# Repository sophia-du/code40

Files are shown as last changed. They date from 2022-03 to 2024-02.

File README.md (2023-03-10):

# code40
Pro-Micro compatible 40% ortholinear keyboard
- [Case Specifications](https://github.com/sophia-du/code40/blob/main/case/README.md)
- [PCB Specifications](https://github.com/sophia-du/code40/blob/main/pcb/README.md)
- [Firmware](https://github.com/sophia-du/code40/blob/main/qmk/README.md)
#
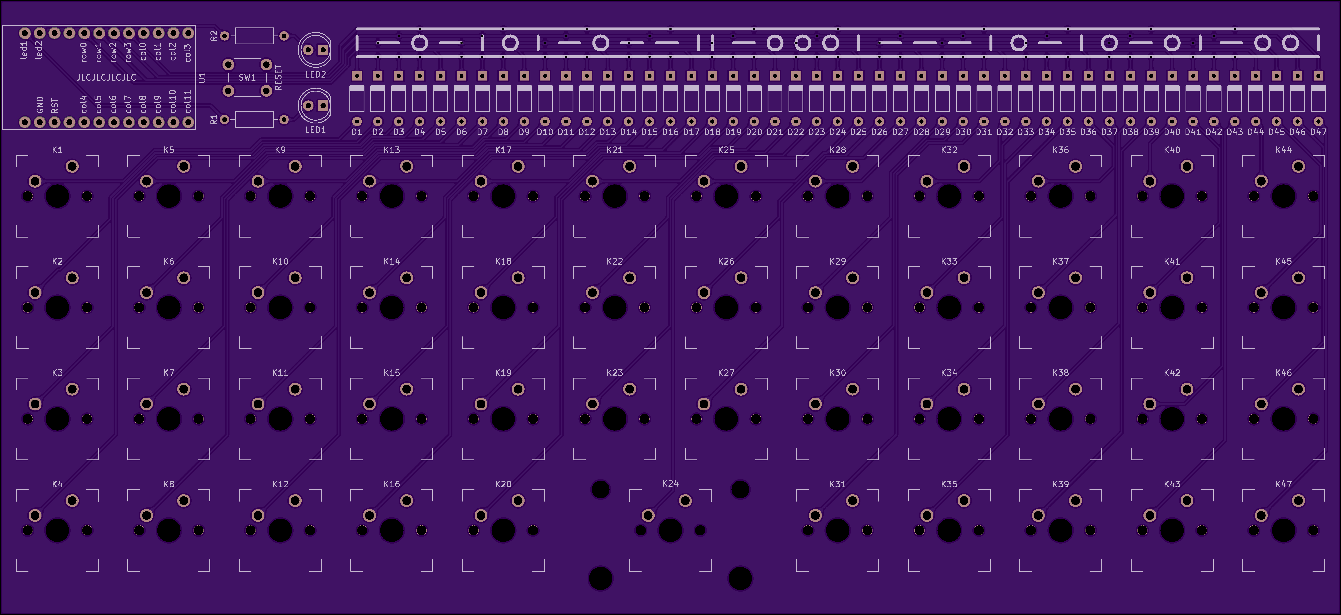
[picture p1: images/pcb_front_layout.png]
PCB

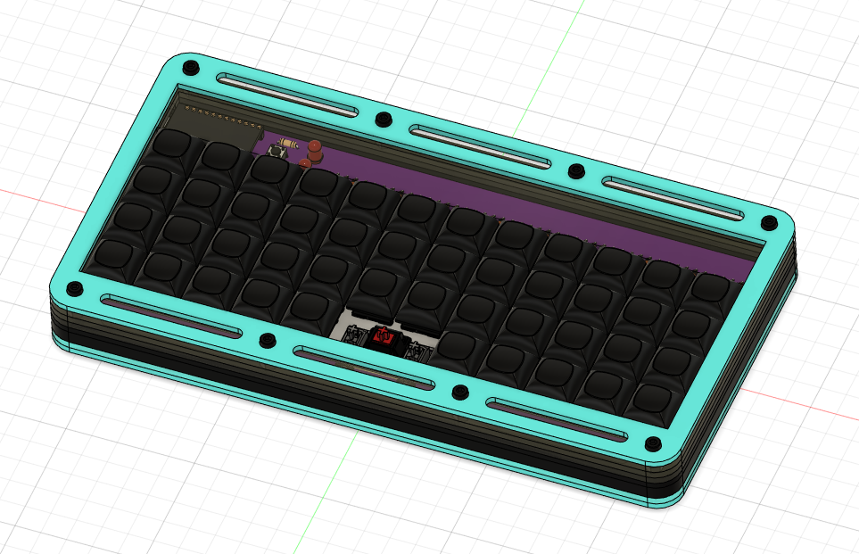
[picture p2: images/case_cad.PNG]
Case

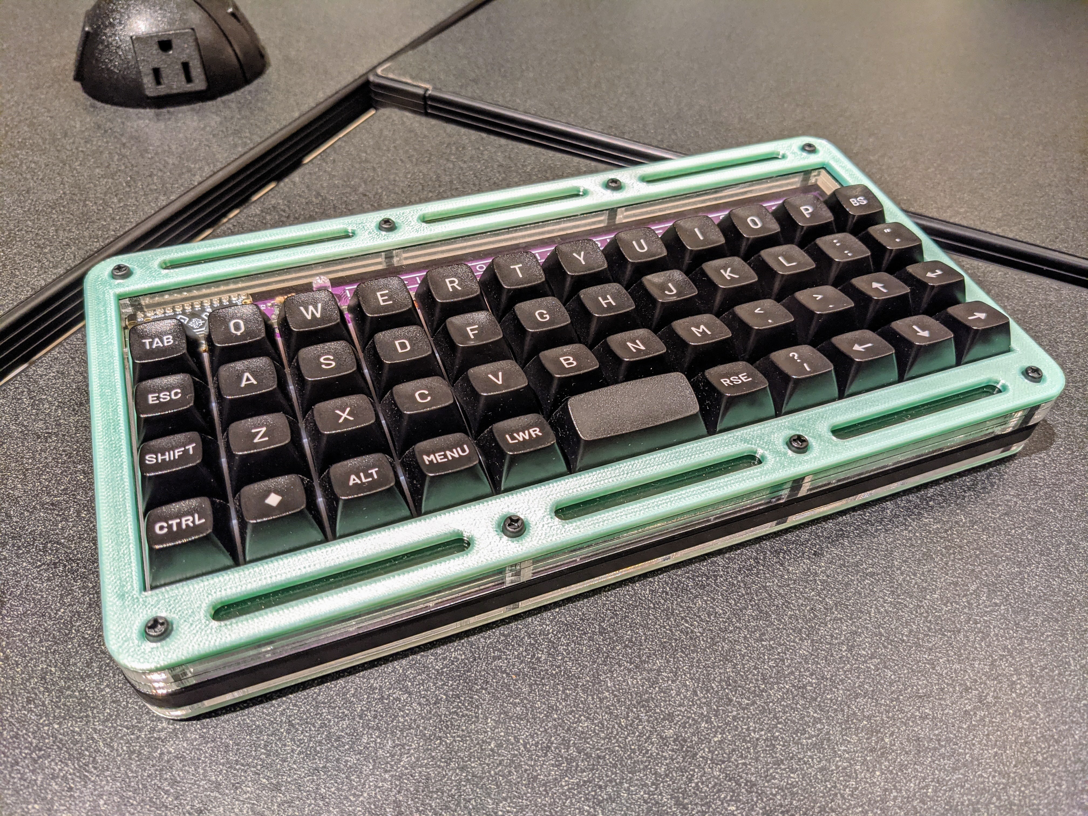
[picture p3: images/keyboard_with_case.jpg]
Case


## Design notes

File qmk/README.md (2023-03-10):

# Firmware
- Hex file: [code40.default.hex](https://github.com/sophia-du/code40/blob/main/qmk/code40_default.hex)
- Follow the [QMK Flashing Guide](https://docs.qmk.fm/#/newbs_flashing)
- Press 6x6 mm button to reset the Pro Micro
## Keymap
From top to bottom: Default, Lower, Raise
\
\
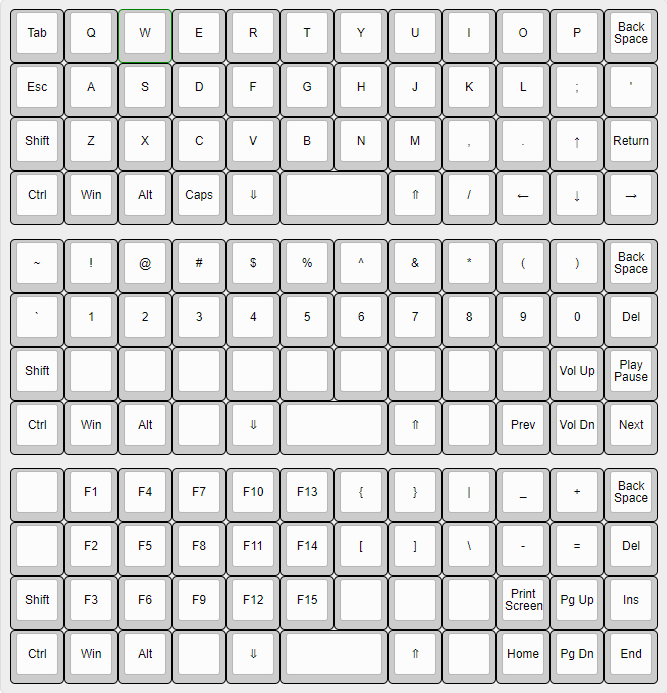
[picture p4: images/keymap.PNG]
keymap

- LED 1 turns on when Lower layer is activated
- LED 2 turns on when Raise layer is activated
- Hold Lower and Raise keys to temporarily switch to respective layers
- Double tap Lower key to toggle Lower layer on/off

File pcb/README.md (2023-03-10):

# PCB Specifications
- Dimensions: 229 x 105 x 1.6 mm
- 2 layers, 1.6 mm thick, 1 oz copper
## Hardware
| Component | Amount |
|---|---|
| Pro-Micro Compatible Microcontroller w/ Headers| 1 |
| 6 x 6 mm Push Button | 1 |
| 100 Ω Through-Hole Resistors | 2 |
| 5 mm Through-Hole LEDs | 2 |
| 1N4148 Diodes | 47 |
| Cherry MX Compatible Switches | 47 |
| 2u PCB Mounted Stabilizers | 1 |
## Assembly
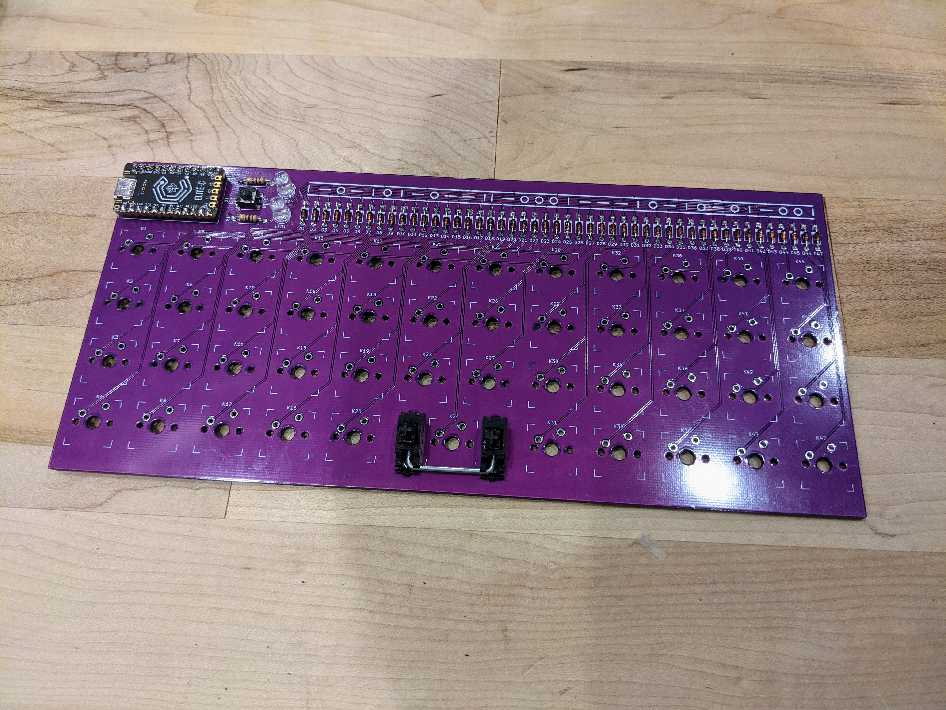
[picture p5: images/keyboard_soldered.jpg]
soldered


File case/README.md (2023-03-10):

# Case Specifications
- 8 layer stacked case
## 3D Printed Layers
- **Layers**: 1, 3, 4, 8
- Plate is optional but recommended for 3 pin switches for stability
- **Print Settings**: 0.20 mm speed, 15% infill on Prusa MK3S
## Acrylic Layers
- **Layers**: 2, 5, 6, 7
- Laser cut
- 3 mm clear acrylic
## Other Hardware
| Component | Amount |
|---|---|
| M3 6 mm Screws | 16 |
| M3 20 mm Standoffs | 8 |
| 10 mm Circular Rubber Feet | 2 |
| 21 mm Circular Rubber Feet | 2 |

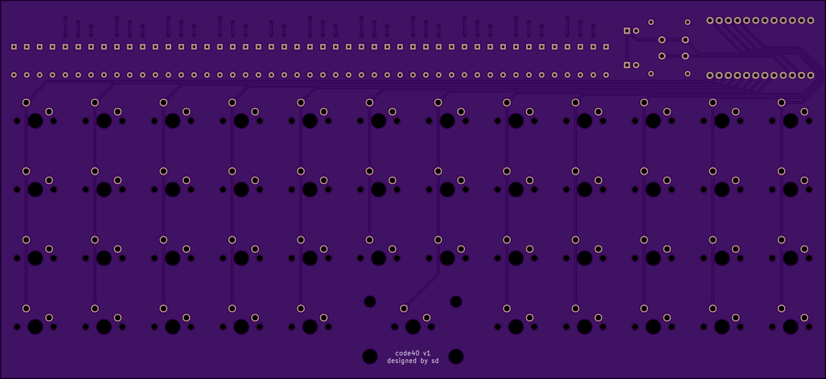
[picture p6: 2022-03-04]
images/pcb_back_layout.png

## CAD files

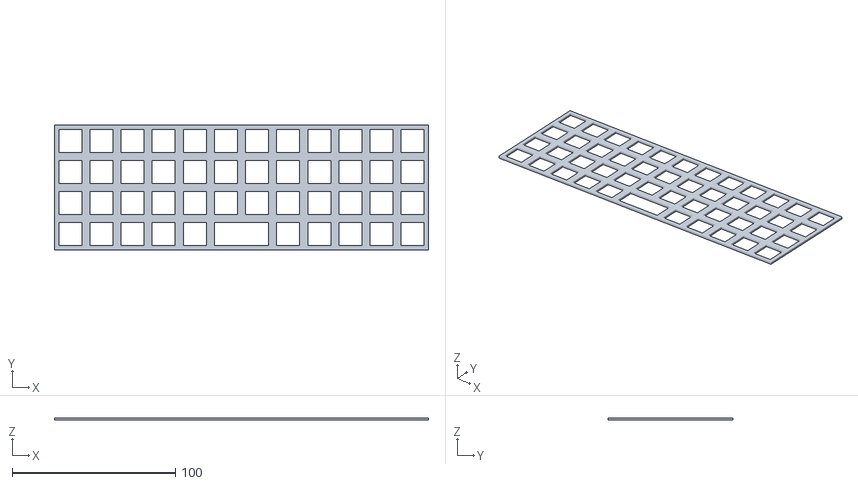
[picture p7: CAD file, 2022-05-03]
case/plate.stl
229.0 x 76.6 x 1.50

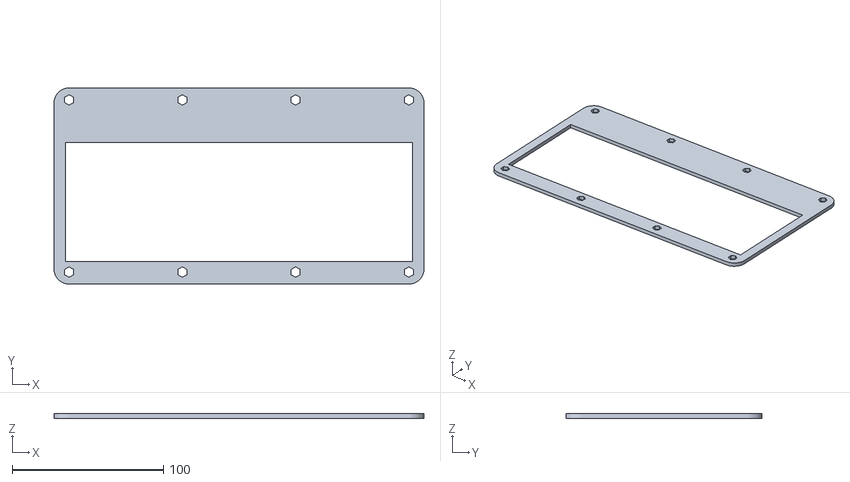
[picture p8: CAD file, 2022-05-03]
case/layer7.stl
245.0 x 130.0 x 3.00

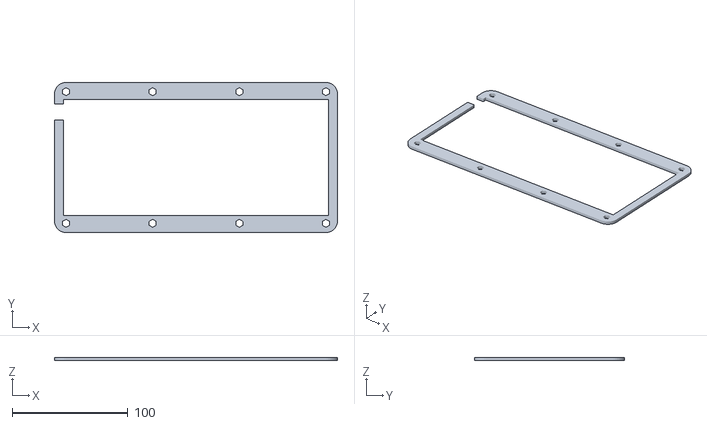
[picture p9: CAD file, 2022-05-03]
case/layer5.stl
245.0 x 130.0 x 3.00

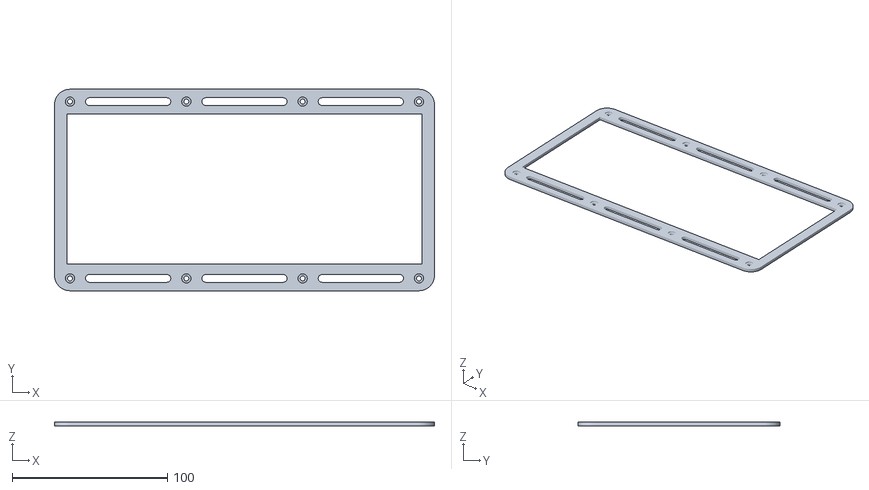
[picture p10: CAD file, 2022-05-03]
case/layer8.stl
245.0 x 130.0 x 2.50

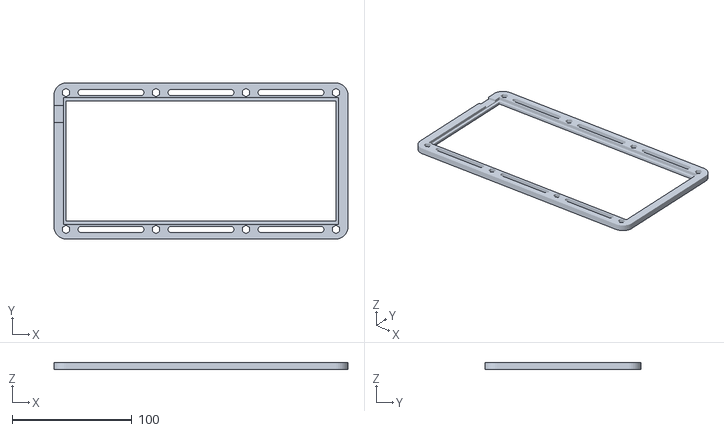
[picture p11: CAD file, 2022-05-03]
case/layer3.stl
245.0 x 130.0 x 5.50

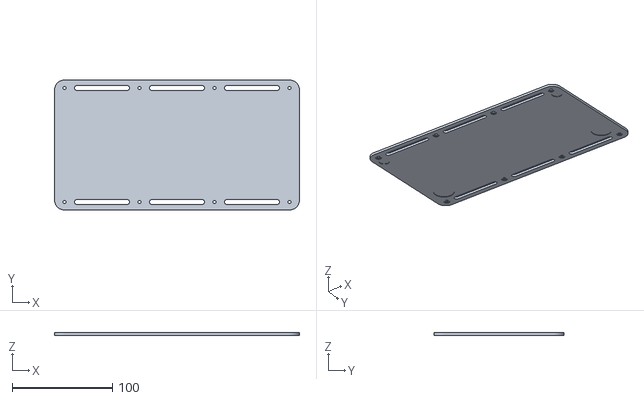
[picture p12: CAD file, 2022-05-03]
case/layer1.stl
245.0 x 130.0 x 2.50

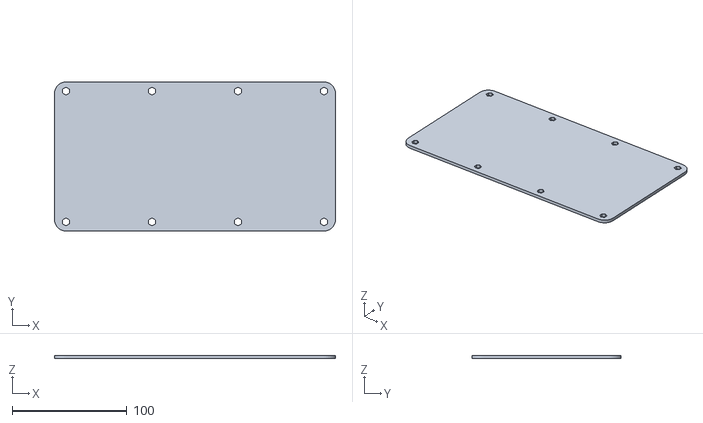
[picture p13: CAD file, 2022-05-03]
case/layer2.stl
245.0 x 130.0 x 3.00

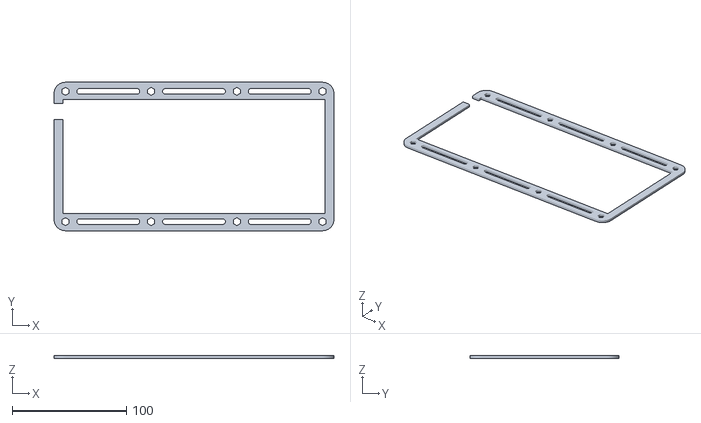
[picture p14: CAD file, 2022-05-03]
case/layer4.stl
245.0 x 130.0 x 2.50

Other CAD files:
case/layer6.stl

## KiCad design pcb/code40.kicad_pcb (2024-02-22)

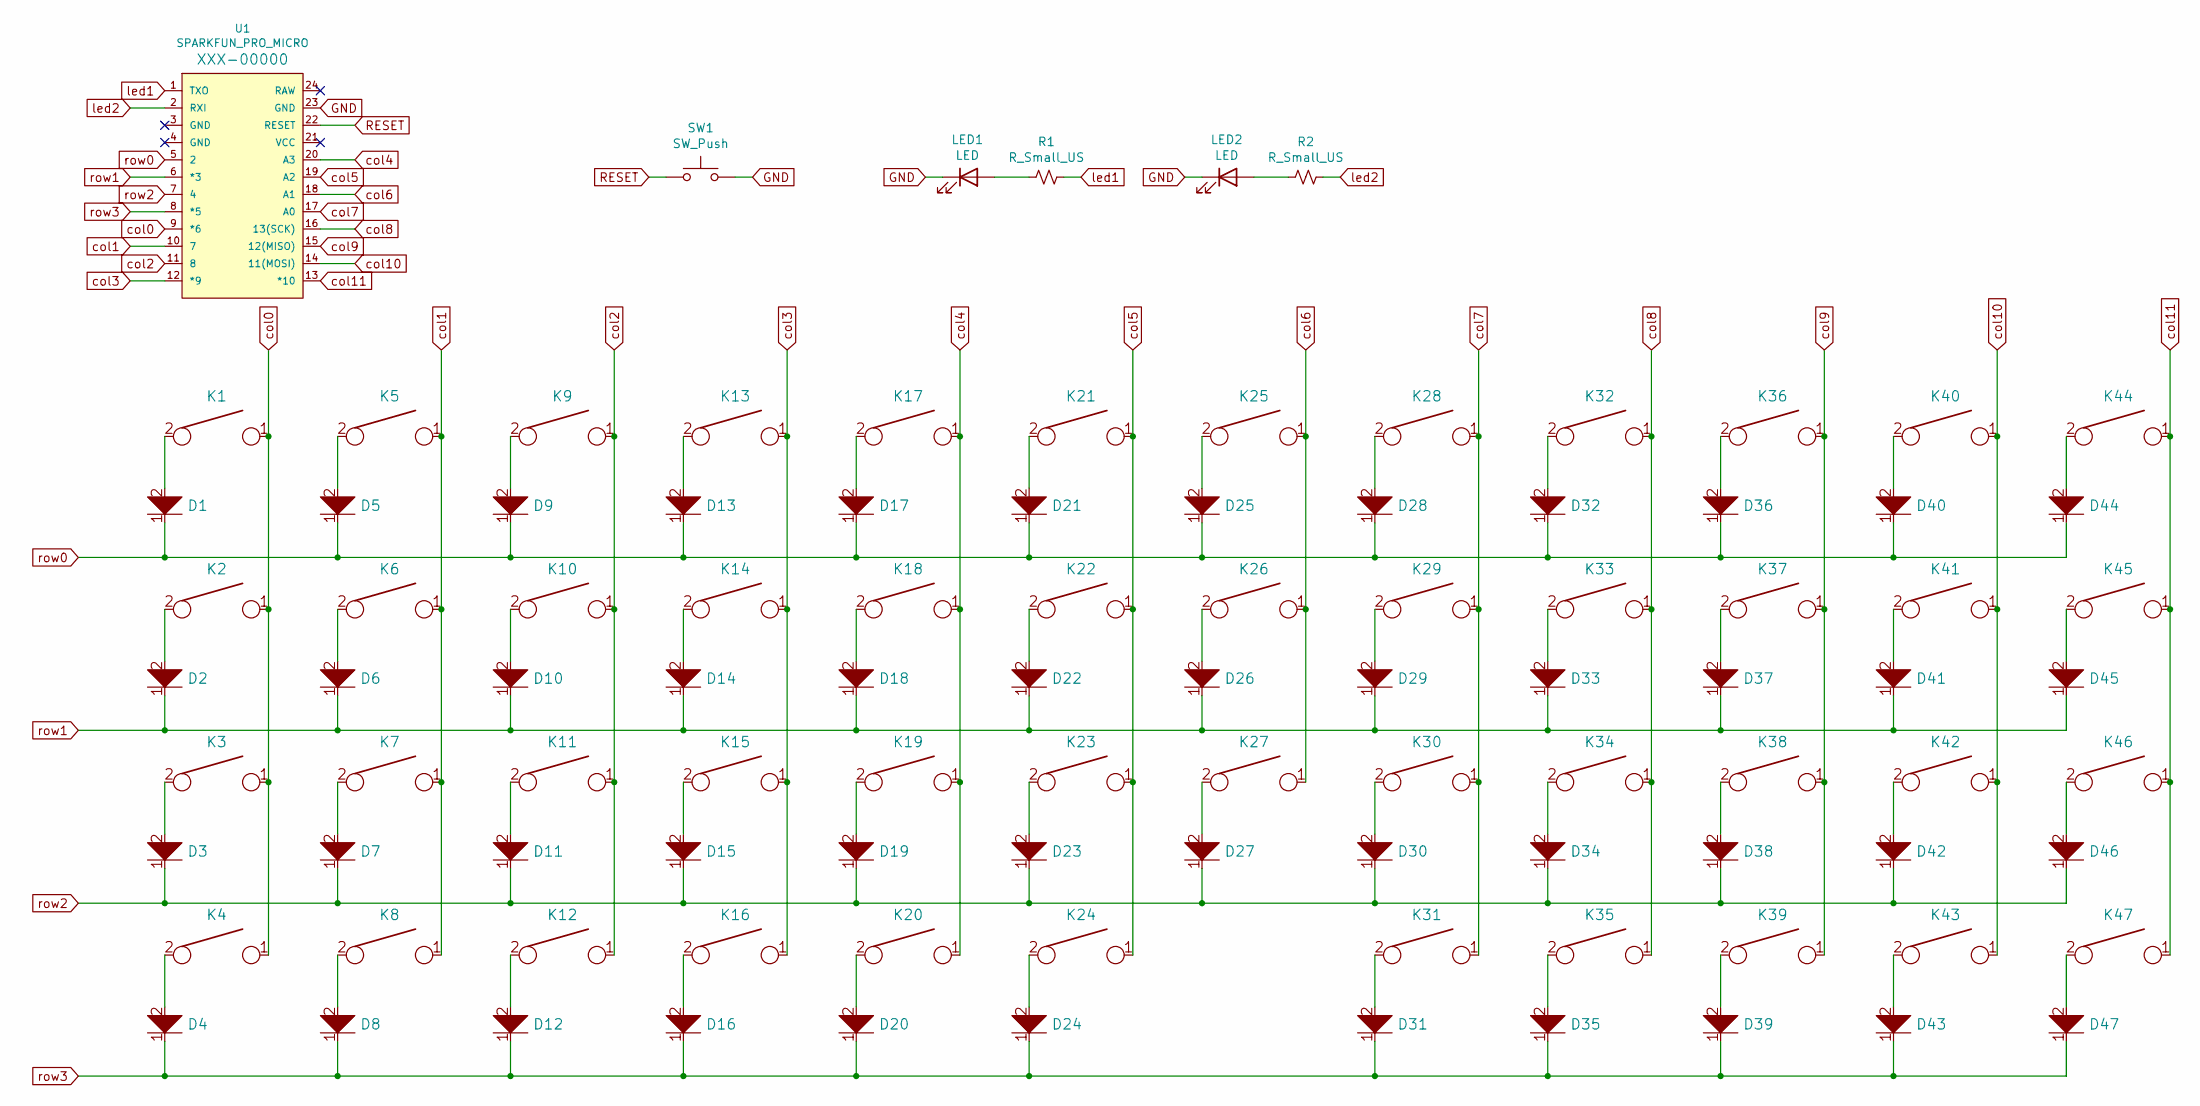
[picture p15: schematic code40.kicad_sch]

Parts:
D1, D2, D3, D4, D5, D6, D7, D8, D9, D10, D11, D12, D13, D14, D15, D16, D17, D18, D19, D20, D21, D22, D23, D24, D25, D26, D27, D28, D29, D30, D31, D32, D33, D34, D35, D36, D37, D38, D39, D40, D41, D42, D43, D44, D45, D46, D47: D; D_axial
K1, K2, K3, K4, K5, K6, K7, K8, K9, K10, K11, K12, K13, K14, K15, K16, K17, K18, K19, K20, K21, K22, K23, K25, K26, K27, K28, K29, K30, K31, K32, K33, K34, K35, K36, K37, K38, K39, K40, K41, K42, K43, K44, K45, K46, K47: KEYSW; SW_Cherry_MX_1.00u_PCB
K24: KEYSW; SW_Cherry_MX_2.00u_PCB
LED1, LED2: LED; LED_D5.0mm
R1, R2: R_Small_US; R_Axial_DIN0207_L6.3mm_D2.5mm_P10.16mm_Horizontal
SW1: SW_Push; SW_PUSH_6mm
U1: SPARKFUN_PRO_MICRO

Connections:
GND: LED1.1 (K), LED2.1 (K), SW1.2, U1.23 (GND)
unnamed: D1.2, K1.2
unnamed: D2.2, K2.2
unnamed: D3.2, K3.2
unnamed: D4.2, K4.2
unnamed: D5.2, K5.2
unnamed: D6.2, K6.2
unnamed: D7.2, K7.2
unnamed: D8.2, K8.2
unnamed: D9.2, K9.2
unnamed: D10.2, K10.2
unnamed: D11.2, K11.2
unnamed: D12.2, K12.2
unnamed: D13.2, K13.2
unnamed: D14.2, K14.2
unnamed: D15.2, K15.2
unnamed: D16.2, K16.2
unnamed: D17.2, K17.2
unnamed: D18.2, K18.2
unnamed: D19.2, K19.2
unnamed: D20.2, K20.2
unnamed: D21.2, K21.2
unnamed: D22.2, K22.2
unnamed: D23.2, K23.2
unnamed: D24.2, K24.2
unnamed: D25.2, K25.2
unnamed: D26.2, K26.2
unnamed: D27.2, K27.2
unnamed: D28.2, K28.2
unnamed: D29.2, K29.2
unnamed: D30.2, K30.2
unnamed: D31.2, K31.2
unnamed: D32.2, K32.2
unnamed: D33.2, K33.2
unnamed: D34.2, K34.2
unnamed: D35.2, K35.2
unnamed: D36.2, K36.2
unnamed: D37.2, K37.2
unnamed: D38.2, K38.2
unnamed: D39.2, K39.2
unnamed: D40.2, K40.2
unnamed: D41.2, K41.2
unnamed: D42.2, K42.2
unnamed: D43.2, K43.2
unnamed: D44.2, K44.2
unnamed: D45.2, K45.2
unnamed: D46.2, K46.2
unnamed: D47.2, K47.2
unnamed: LED1.2 (A), R1.2
unnamed: LED2.2 (A), R2.2
RESET: SW1.1, U1.22 (RESET)
col0: K1.1, K2.1, K3.1, K4.1, U1.9 (*6)
col1: K5.1, K6.1, K7.1, K8.1, U1.10 (7)
col2: K9.1, K10.1, K11.1, K12.1, U1.11 (8)
col3: K13.1, K14.1, K15.1, K16.1, U1.12 (*9)
col4: K17.1, K18.1, K19.1, K20.1, U1.20 (A3)
col5: K21.1, K22.1, K23.1, K24.1, U1.19 (A2)
col6: K25.1, K26.1, K27.1, U1.18 (A1)
col7: K28.1, K29.1, K30.1, K31.1, U1.17 (A0)
col8: K32.1, K33.1, K34.1, K35.1, U1.16 (13(SCK))
col9: K36.1, K37.1, K38.1, K39.1, U1.15 (12(MISO))
col10: K40.1, K41.1, K42.1, K43.1, U1.14 (11(MOSI))
col11: K44.1, K45.1, K46.1, K47.1, U1.13 (*10)
led1: R1.1, U1.1 (TXO)
led2: R2.1, U1.2 (RXI)
row0: D1.1, D5.1, D9.1, D13.1, D17.1, D21.1, D25.1, D28.1, D32.1, D36.1, D40.1, D44.1, U1.5 (2)
row1: D2.1, D6.1, D10.1, D14.1, D18.1, D22.1, D26.1, D29.1, D33.1, D37.1, D41.1, D45.1, U1.6 (*3)
row2: D3.1, D7.1, D11.1, D15.1, D19.1, D23.1, D27.1, D30.1, D34.1, D38.1, D42.1, D46.1, U1.7 (4)
row3: D4.1, D8.1, D12.1, D16.1, D20.1, D24.1, D31.1, D35.1, D39.1, D43.1, D47.1, U1.8 (*5)

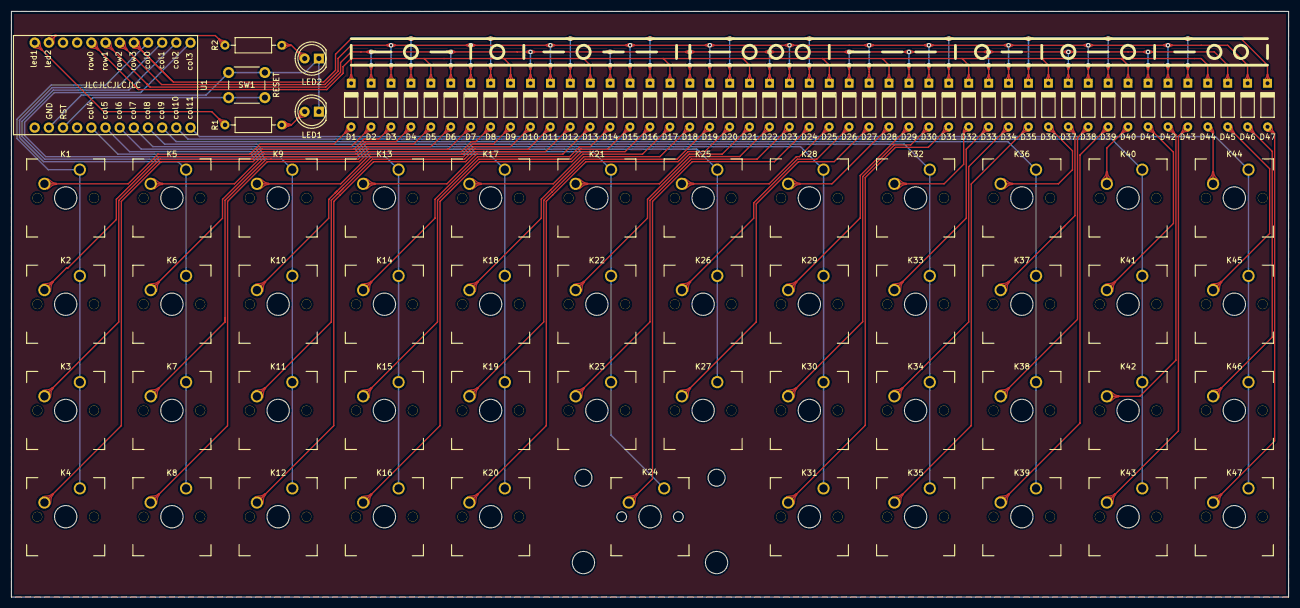
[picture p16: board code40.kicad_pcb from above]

Board: 2 copper layers, 229.0 x 105.0 mm, 101 parts (1 on the bottom side), 69 nets.

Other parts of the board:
ST1: Stabilizer_Cherry_MX_2.00u

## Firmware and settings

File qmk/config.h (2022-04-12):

#ifndef CONFIG_H
#define CONFIG_H

#include "config_common.h"

/* USB Device descriptor parameter */
#define VENDOR_ID       0xFEED
#define PRODUCT_ID      0x6060
#define DEVICE_VER      0x0001
#define MANUFACTURER    sd
#define PRODUCT         code40
#define DESCRIPTION     pro-micro compatible ortholinear 40% keyboard

/* key matrix size */
#define MATRIX_ROWS 4
#define MATRIX_COLS 12

/* key matrix pins */
#define MATRIX_ROW_PINS { D1, D0, D4, C6 }
#define MATRIX_COL_PINS { D7, E6, B4, B5, F4, F5, F6, F7, B1, B3, B2, B6 }
#define UNUSED_PINS

/* COL2ROW or ROW2COL */
#define DIODE_DIRECTION COL2ROW

/* Set 0 if debouncing isn't needed */
#define DEBOUNCING_DELAY 5

#define TAPPING_TOGGLE 2

#endif
